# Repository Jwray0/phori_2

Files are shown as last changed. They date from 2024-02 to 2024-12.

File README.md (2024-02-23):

# PhobGCCv2-HW fork
Seperate repository for the hardware used in the phori v2

The PhobGCC v2.0 board is licensed under CERN Open Hardware Licence Version 2 - Strongly Reciprocal.
This means that any changes made to the board should be made public and CHANGES.txt be updated to reflect said changes.

phori v2 is developed for the hori gamecube controller. 

https://github.com/PhobGCC/PhobGCCv2-HW

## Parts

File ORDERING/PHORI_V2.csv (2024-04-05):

Comment | Designator | Footprint | LCSC
1k | R16,R18 | R_0402_1005Metric | C11702
USB_B_Micro | J9 | USB_Micro-B_Amphenol_10118194_Horizontal | C132563
27 | R20,R21 | R_0402_1005Metric | C138021
CUS10S30,H3F | D1,D5 | D_SOD-323 | C146335
Q_PMOS_GDS | Q2 | SOT-23 | C15127
100n | C17,C19,C20,C22,C24,C25,C26,C27,C28,C29,C30,C31,C32 | C_0402_1005Metric | C1525
27p | C14,C15 | C_0402_1005Metric | C1557
10u | C16,C18 | C_0805_2012Metric | C15850
316 | R10,R19,R24,R25 | R_0402_1005Metric | C159037
0.047u | C3,C4,C5,C6,C7,C8 | C_0603_HandSoldering | C1622
RP2040 | U8 | RP2040-QFN-56 | C2040
Q_NMOS_GSD | Q1,Q3 | SOT-23 | C20917
100R | R11,R12 | R_0603_1608Metric_Pad0.98x0.95mm_HandSolder | C22775
2k | R3,R4,R5,R6 | R_0603_1608Metric_Pad0.98x0.95mm_HandSolder | C22975
100k | R17 | R_0603_1608Metric_Pad0.98x0.95mm_HandSolder | C25803
10k | R13,R14,R15 | R_0603_1608Metric_Pad0.98x0.95mm_HandSolder | C25804
DRV5055A2xDBZxQ1 | U10,U11,U4,U3 | SOT-23 | C266131
BOOTSEL | S1 | SW_TS-1187A-B-A-B | C318884
180 | R1,R2,R7,R8,R9 | R_0402_1005Metric | C38941
Crystal_GND24 | Y1 | Crystal_SMD_3225-4Pin_3.2x2.5mm | C403945
1u | C21,C23 | C_0402_1005Metric | C52923
MCP3002 | U1,U2 | SOIC-8_3.9x4.9mm_P1.27mm | C56997
AMS1117-3.3 | U6 | SOT-223-3_TabPin2 | C6186
Fuse | F1 | Fuse_1206_3216Metric | C69680
M7C | D2 | D_SOD-323 | C8598
W25Q128JVS | U7 | SOIC-8_5.23x5.23mm_P1.27mm | C97521
47u | C1 | CP_EIA-3528-12_Kemet-T | C136751
USBLC6-2P6 | U12,U13 | SOT-666

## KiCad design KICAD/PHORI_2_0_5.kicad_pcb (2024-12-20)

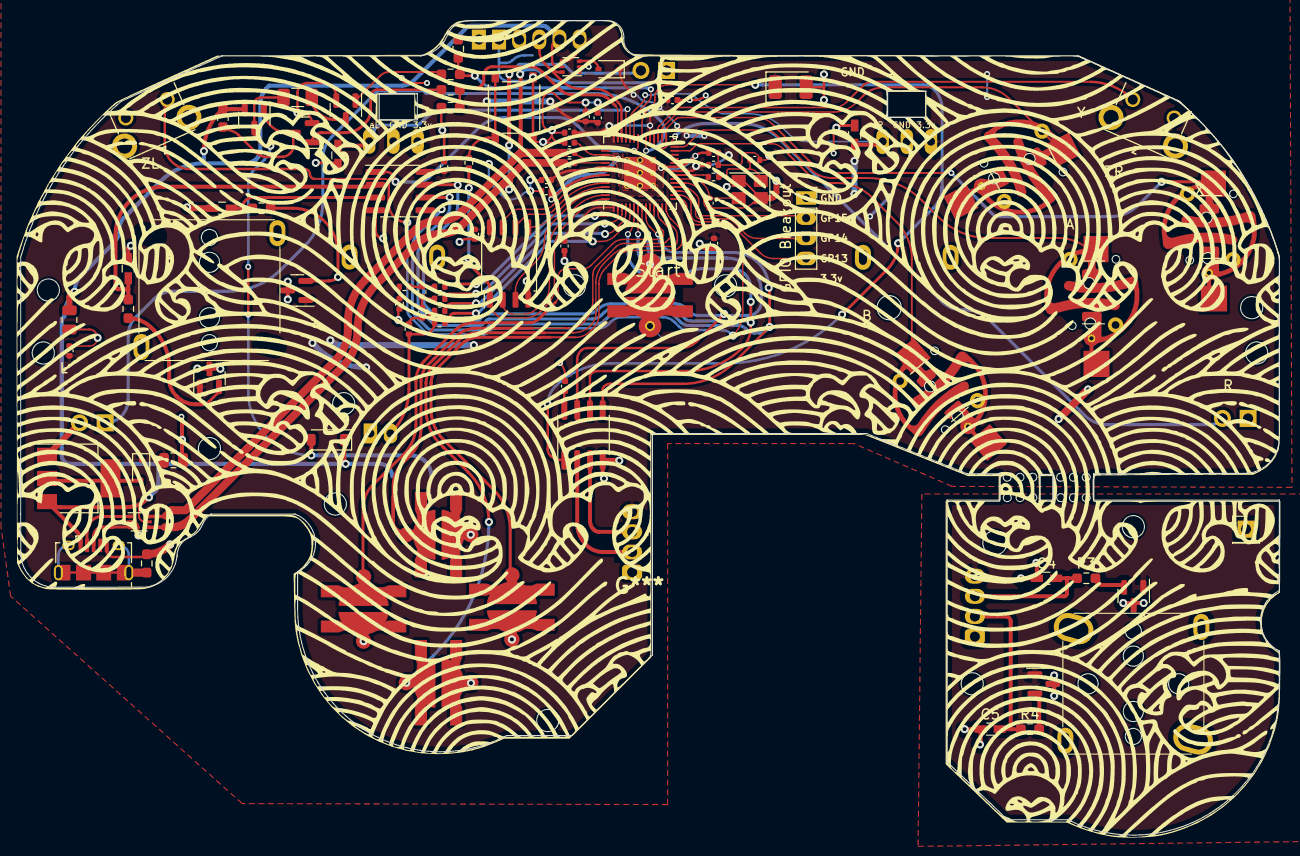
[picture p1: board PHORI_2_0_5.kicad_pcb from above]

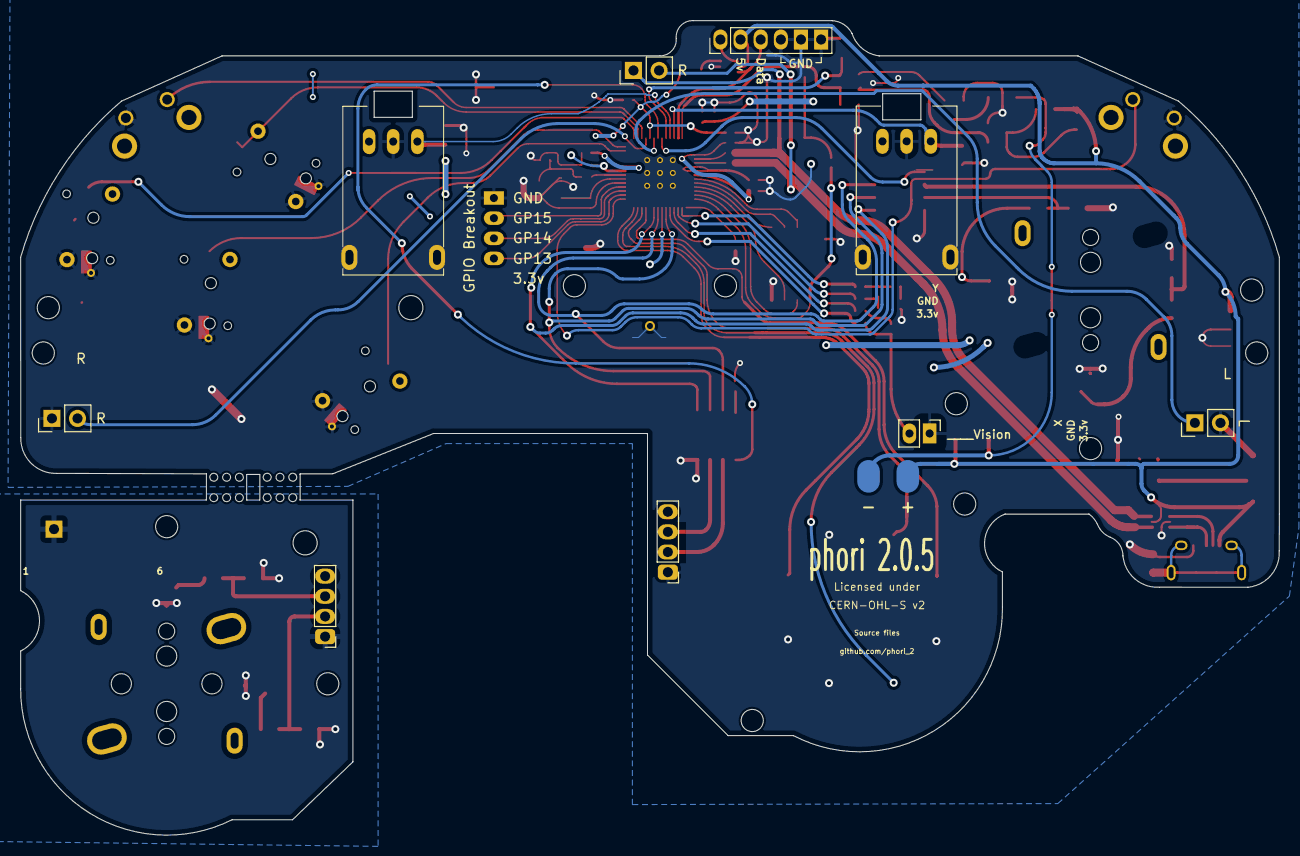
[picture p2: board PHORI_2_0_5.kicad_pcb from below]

Board: 2 copper layers, 125.0 x 80.9 mm, 113 parts (12 on the bottom side), 74 nets.

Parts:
C1: 47u; CP_EIA-3528-12_Kemet-T
C3, C4, C5, C6, C7, C8: 0.047u; C_0603_HandSoldering
C14, C15: 27p; C_0402_1005Metric
C16, C18: 10u; C_0805_2012Metric
C17, C19, C20, C22, C24, C25, C26, C27, C28, C29, C30, C31, C32: 100n; C_0402_1005Metric
C21, C23: 1u; C_0402_1005Metric
D1, D5: CUS10S30,H3F; D_SOD-323
D2: M7C; D_SOD-123
F1: Fuse; Fuse_1206_3216Metric
H5, H6: 1.8mm; MountingHole_1.8mm
H7, H7#2: 2.4mm; MountingHole_2.4mm
H8, H8#2, H8#3, H8#4, H8#5, H8#6, H8#7, H9: 2.2mm; MountingHole_2.2mm
H10, H10#2: MountingHole; MountingHole_1.8mm
H12, H13: MountingHole; MountingHole_2.0mm
H14, H15: MouseBite; breakaway-mousebites-double
J1: Conn_01x06_Female; GCC_Header_Straight_1x06_Pitch2.00mm
J2: Conn_01x02; PinHeader_1x02_P2.00mm_Vertical
J2#2: Conn_01x04_Female; PinHeader_1x04_P2.00mm_Vertical
J4: Conn_01x01; PinHeader_1x01_P2.54mm_Vertical
J4#2: Conn_01x04_Male; PinHeader_1x04_P2.00mm_Vertical
J5: Rumble; rumble_pins
J6: PinSocket_1x04_P2.00mm_Vertical
J9: USB_B_Micro; USB_Micro-B_Amphenol_10118194_Horizontal
Q1, Q3: Q_NMOS_GSD; SOT-23
Q2: Q_PMOS_GDS; SOT-23
R1, R2, R7, R8, R9: 180; R_0402_1005Metric
R3, R4, R5, R6: 2k; R_0603_1608Metric_Pad0.98x0.95mm_HandSolder
R10, R19, R24, R25: 316; R_0402_1005Metric
R11, R12: 100R; R_0603_1608Metric_Pad0.98x0.95mm_HandSolder
R13, R14, R15: 10k; R_0603_1608Metric_Pad0.98x0.95mm_HandSolder
R16, R18: 1k; R_0402_1005Metric
R17: 100k; R_0603_1608Metric_Pad0.98x0.95mm_HandSolder
R20, R21: 27; R_0402_1005Metric
RV1, RV2: R_POT_MountingPin; GCC_Slider
S1: BOOTSEL; SW_TS-1187A-B-A-B
SW1, SW1#2: A; ABXY_Contact_Omron_Switch_b3F
SW2: B; ABXY_Contact_Omron_Switch_b3F_v2
SW4: Y; ABXY_Contact_Omron_Switch_b3F_v2
SW5: Start; Dpad_Contact_TL3315NF_2
SW6: L; Pin_Header_Straight_1x02_Pitch2.54mm
SW7, SW7#2: R; Pin_Header_Straight_1x02_Pitch2.54mm
SW8, SW8#2: Z; Z_Switch_Edge_Omron
SW10, SW10#2: Dup; Dpad_Contact_TL3315NF_2
SW11, SW11#2: Dright; Dpad_Contact_TL3315NF_2
U1, U1#2: MCP3002; SOIC-8_3.9x4.9mm_P1.27mm
U2: Stickbox_Assembly_Main; GCC_Stickbox_Hall_Only
U3, U4, U10, U11: DRV5055Z3QDBZT; SOT-23
U5: Stickbox_Assembly; GCC_Stickbox_Hall_Only
U6: AMS1117-3.3; SOT-223-3_TabPin2
U7: W25Q128JVS; SOIC-8_5.23x5.23mm_P1.27mm
U8: RP2040; RP2040-QFN-56
U12, U13: USBLC6-2P6; SOT-666
Y1: Crystal_GND24; Crystal_SMD_3225-4Pin_3.2x2.5mm

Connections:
+1V1: C19.1, C20.1, C21.1, U8.23 (DVDD), U8.45 (VREG_VOUT), U8.50 (DVDD)
+3V3: C1.1, C17.1, C18.1, C22.1, C23.1, C24.1, C25.1, C26.1, C27.1, C28.1, C29.1, C30.1, C31.1, D1.1 (K), D5.1 (K), J1.1, J2#2.4, RV1.1 (V+), RV2.1 (V+), U1#2.8 (VDD/VREF), U3.1 (VCC), U4.1 (VCC), U7.8 (VCC), U8.1 (IOVDD), U8.10 (IOVDD), U8.22 (IOVDD), U8.33 (IOVDD), U8.42 (IOVDD), U8.43 (ADC_AVDD), U8.44 (VREG_IN), U8.48 (USB_VDD), U8.49 (IOVDD), U13.4
+5V: C16.1, D2.1 (K), J1.2, J5.1, J9.1, Q2.2 (S), R13.2, U6.3 (VI), U12.5, U13.5
A: SW1#2.1, U8.28 (GPIO17)
B: SW2.1, U8.27 (GPIO16)
Brake: R12.1, R14.2, U8.41 (GPIO29_ADC3)
CLK: U1.7 (CLK), U1#2.7 (CLK), U8.8 (GPIO6)
CS1: U1#2.1 (~CS/SHDN), U8.36 (GPIO24)
CS2: U1.1 (~CS/SHDN), U8.35 (GPIO23)
C_X_Filt: C5.1, R4.1
C_Y_Filt: C4.1, J4#2.3, R3.1
Ddown: SW10#2.1, U8.13 (GPIO10)
Din: U1.5 (DIN), U1#2.5 (DIN), U8.9 (GPIO7)
Dleft: SW11.1, U8.11 (GPIO8)
Dout: U1.e (DOUT), U1#2.6 (DOUT), U8.6 (GPIO4)
Dright: SW11#2.1, U8.14 (GPIO11)
Dup: SW10.1, U8.12 (GPIO9)
GCC_DATA: J1.3, U8.40 (GPIO28_ADC2), U13.6
GND: C1.2, C3.2, C6.2, C7.2, C8.2, C14.2, C16.2, C17.2, C18.2, C19.2, C20.2, C21.2, C22.2, C23.2, C24.2, C25.2, C26.2, C27.2, C28.2, C29.2, C30.2, C31.2, C32.2, J1.4, J1.5, J1.6, J2.1, J2#2.1, J6.1, J9.5, Q1.2 (S), Q3.2 (S), R1.2, R14.1, R15.1, R17.2, RV1.2 (GND), RV2.2 (GND), S1.A, S1.B, SW1.2, SW1#2.2, SW2.2, SW4.2, SW5.2, SW5.3, SW6.2, SW7#2.1, SW8.2, SW8#2.1, SW10.2, SW10#2.2, SW11.2, SW11#2.2, U1.4 (VSS), U3.3 (GND), U4.3 (GND), U6.1 (GND), U7.4 (GND), U8.19 (TESTEN), U8.57 (GND), U12.2, U13.2, Y1.2, Y1.4
GPIO13: J6.4, U8.16 (GPIO13)
GPIO14: J6.3, U8.17 (GPIO14)
GPIO15: J6.2, U8.18 (GPIO15)
H1XS: R6.2, U4.2 (OUT)
H1YS: R5.2, U3.2 (OUT)
H2XS: R4.2, U10.2 (OUT)
H2YS: R3.2, U11.2 (OUT)
L: SW6.1, U8.34 (GPIO22)
Ladder1: R10.2, U8.2 (GPIO0)
Ladder2: R19.2, U8.3 (GPIO1)
Ladder3: R24.2, U8.4 (GPIO2)
Ladder4: R25.2, U8.5 (GPIO3)
Lanalog: C7.1, RV1.3 (Signal), U8.39 (GPIO27_ADC1)
LeftZ: SW8#2.2, U8.15 (GPIO12)
unnamed: R18.2, Y1.1
unnamed: D1.2 (A), U6.2 (VO)
unnamed: D2.2 (A), J5.2, Q2.3 (D)
unnamed: D5.2 (A), U13.3
unnamed: F1.2, Q3.3 (D)
unnamed: J9.6, R17.1
unnamed: Q1.1 (G), R12.2
unnamed: Q1.3 (D), Q2.1 (G), R13.1
unnamed: Q3.1 (G), R11.2
unnamed: R1.1, R2.2
unnamed: R2.1, R7.2, R10.1
unnamed: R7.1, R8.2, R19.1
unnamed: R20.2, U8.47 (USB_DP)
unnamed: R21.2, U8.46 (USB_DM)
unnamed: R8.1, R9.2, R24.1
QSPI_SCLK: U7.6 (CLK), U8.52 (QSPI_SCLK)
QSPI_SD0: U7.5 (DI(IO0)), U8.53 (QSPI_SD0)
QSPI_SD1: U7.2 (DO(IO1)), U8.55 (QSPI_SD1)
QSPI_SD2: U7.3 (IO2), U8.54 (QSPI_SD2)
QSPI_SD3: U7.7 (IO3), U8.51 (QSPI_SD3)
QSPI_SS: R16.1, U7.1 (~CS), U8.56 (QSPI_SS)
R: SW7#2.2, U8.32 (GPIO21)
Ranalog: C3.1, RV2.3 (Signal), U8.38 (GPIO26_ADC0)
Rumble: R11.1, R15.2, U8.37 (GPIO25)
Start: SW5.1, U8.7 (GPIO5)
Stick_filt_x: C8.1, R6.1
Stick_filt_y: C6.1, R5.1
USB_BOOT: R16.2, S1.C, S1.D
USB_D+: R20.1, SW7.2, U12.4
USB_D+_Raw: J9.3, U12.3
USB_D-: R21.1, SW7.1, U12.6
USB_D-_Raw: J9.2, U12.1
V: J2.2, R9.1, R25.1
VCC: C32.1, U1.8 (VDD/VREF)
X: SW1.1, U8.29 (GPIO18)
XIN: C14.1, U8.20 (XIN), Y1.3
XOUT: R18.1, U8.21 (XOUT)
Y: SW4.1, U8.30 (GPIO19)
Z: SW8.1, U8.31 (GPIO20)
gnd: C4.2, C5.2, J4.1, J4#2.1, U10.3 (GND), U11.3 (GND)
vcc: J4#2.4, U10.1 (VCC), U11.1 (VCC)

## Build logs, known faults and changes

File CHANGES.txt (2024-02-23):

Reconfigured the Phob V2 to fit into the formfactor of the Hori Gamecube Controller.
Moved C-Stick ADC to mainboard
added throughholes for B3F switches
Curved traces
added Tac  solder pads for start
added mouseclick through holes

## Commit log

2024-02-23 adding KiKad filed and JLC ordering
    Crude BOM and CPL
    Will need to clean up later
    [BOM-PHORI_2_0_5.csv, PHORI_2_0_5.kicad_pcb, PHORI_2_0_5.kicad_sch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]
2024-02-23 updated back Silkscreen
    [BOM-PHORI_2_0_5.csv, PHORI_2_0_5.kicad_pcb]
2024-02-23 fixed stick placement
    [BOM-PHORI_2_0_5.csv, PHORI_2_0_5.kicad_pcb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]
2024-02-23 Updated JLC files
    [BOM-PHORI_2_0_5.csv, PHORI_2_0_5.kicad_pcb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]
2024-02-24 Better BOM
    [BOM-PHORI_2_0_5.csv, PHORI_2_0_5.kicad_pcb, PHORI_V2.csv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]
2024-03-08 fixed stick hole
    [BOM-PHORI_2_0_5.csv, PHORI_2_0_5.kicad_pcb]
2024-03-08 added d+- holes
    [PHORI_2_0_5.kicad_pcb]
2024-04-05 Updated CPL
    Added updated CPL and Gerber for ordering at JLC
    [BOM-PHORI_2_0_5.csv, PHORI_2_0_5.kicad_pcb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]
2024-04-26 KIKAD 8
    Kikad 8 update and some small fixes
    [PHORI_2_0_5.kicad_pcb, positions.csv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]
2024-12-20 GND on Rp2040
    [PHORI_2_0_5.kicad_pcb, PHORI_2_0_5.kicad_sch]
2024-12-20 new gerber
    [PHORI_2_0_5.kicad_pcb]

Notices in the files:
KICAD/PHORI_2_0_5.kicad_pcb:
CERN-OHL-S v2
